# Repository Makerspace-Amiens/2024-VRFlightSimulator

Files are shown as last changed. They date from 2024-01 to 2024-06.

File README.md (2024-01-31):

# Simulateur de Vol

Template pour la création d'un repo type projet pour le MakerSpace. Doc gérée via le thème [Just-The-Docs](https://just-the-docs.com) en vanilla.

## Bienvenue sur Notre Projet

Ce repository est le cœur de notre projet. Ici, vous trouverez toutes les ressources nécessaires pour comprendre, utiliser et contribuer à notre projet.

### Contenu du Repository

- **Documentation :** Toutes les documentations techniques et guides d'utilisation sont disponibles dans le dossier `docs`. Voir le site de doc associé. 
- **project :** Toutes les sources de notre projet.

### Comment Utiliser ce Repository ?

- Pour commencer, consultez la documentation dans le dossier `docs`.
- Si vous souhaitez contribuer au projet, veuillez lire nos directives de contribution.

## Contribution

Nous accueillons et apprécions toute contribution. Si vous souhaitez contribuer, veuillez consulter notre guide de contribution pour connaître nos attentes et notre processus.

## Contact

Si vous avez des questions ou des suggestions, n'hésitez pas à nous contacter.

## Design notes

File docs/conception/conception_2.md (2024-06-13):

---
layout: default
title: Commande de gaz
parent: Conception et prototypage
nav_order: 2
---

# Conception et prototypage de la commande de gaz

## Mécanisme de frein

La première contrainte rencontrée dans la conception de la commande de gaz correspond au frein des poignées lorsqu'elles sont poussées ou tirées. Pour cela, nous nous sommes orientés dans un premier temps vers un système de vérins pneumatiques fixés sous les axes de rotation des deux poignées. Malheureusement, ce système était trop encombrant et couteux dans notre application. Nous nous sommes alors orientés vers l'utilisation de joints de plomberies mis en contrainte entre une pièce fixe et la poignée. 

Nous avons donc développé un système de frein sur mesure afin de répondre spécifiquement à nos attentes. La vis fait office d'axe de rotation et permet de compresser le joint entre la pièce fixe et la poignée, l'intensité du frein peut alors être réglée individuellement sur chaque poignée. Un écrou est inséré dans la commande de gaz et un contre-écrou permet d'entrainer la vis lors de la rotation de la poignée. Une pièce s'emboitant sur ce contre-écrou et soutenue par un roulement est destinée à accueillir l'aimant permettant de mesurer la rotation de l'axe et donc le mouvement de la poignée une fois de plus à l'aide du capteur à effet Hall AS5600.

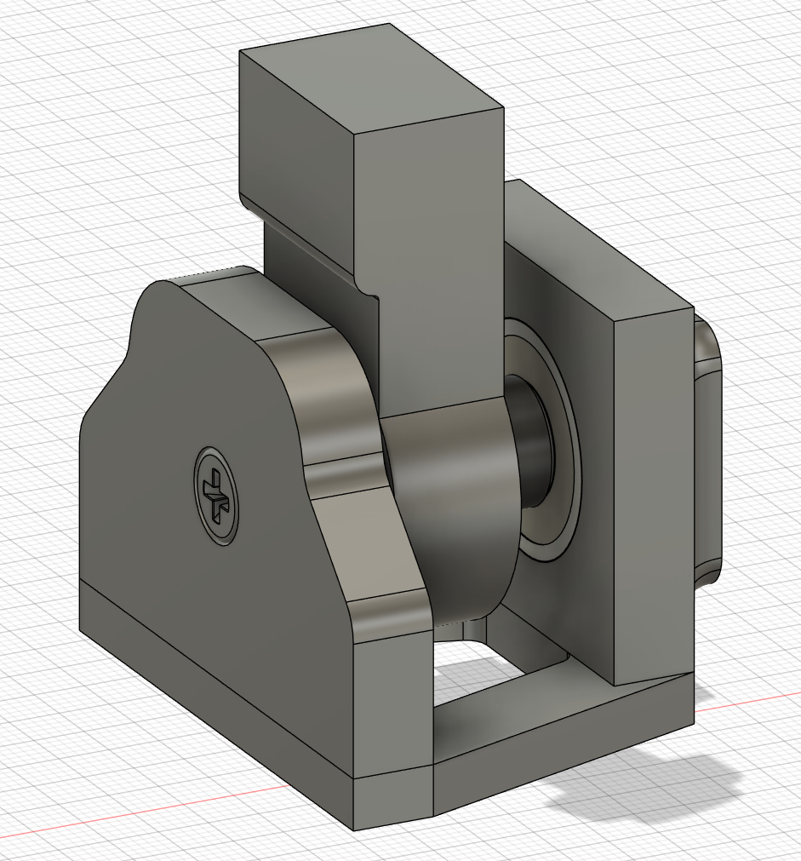
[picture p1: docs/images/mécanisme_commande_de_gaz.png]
Mécanisme cmd gaz 1


*Prototype du mécanisme de frein*

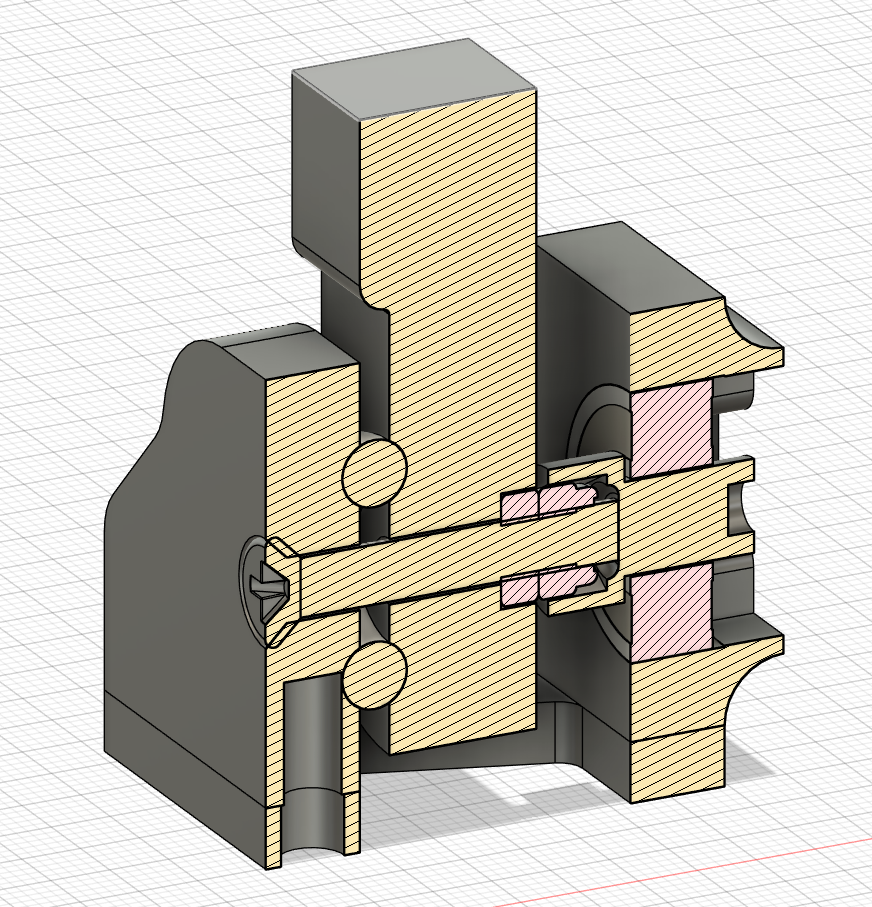
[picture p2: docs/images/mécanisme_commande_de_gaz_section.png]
Mécanisme cmd gaz 2


*Analyse de section du prototype du mécanisme de frein*

Nous avons ensuite prototypé ce mécanisme afin de valider son fonctionnement et son intégration définitive dans la commande de gaz.

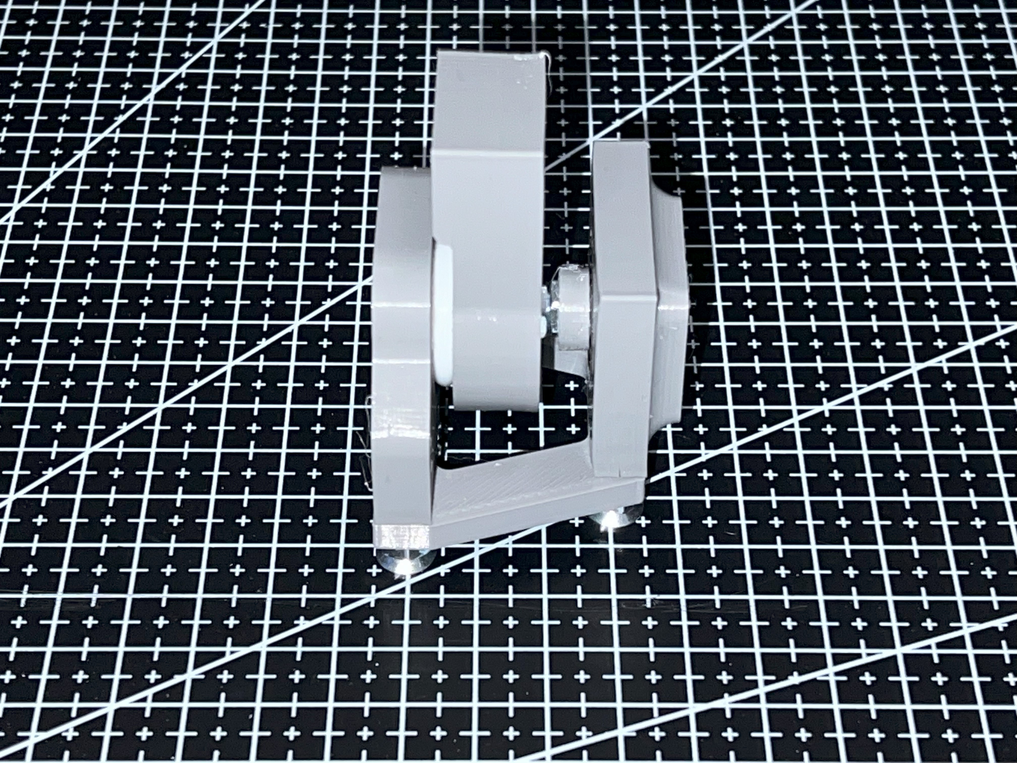
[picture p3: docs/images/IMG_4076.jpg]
Mécanisme cmd gaz 3


*Prototype du mécanisme de frein*

## Modélisation de la commande

Lors de la phase de modélisation de la commande de gaz, nous avons dans un premier temps reproduit à l'échelle 1:1 les poignées de commande de gaz d'un avion de combat A-10C tout en prenant en compte le passage des câbles des futurs composants électroniques, puis avons intégré ces commandes sur notre mécanisme de frein mis en miroir.

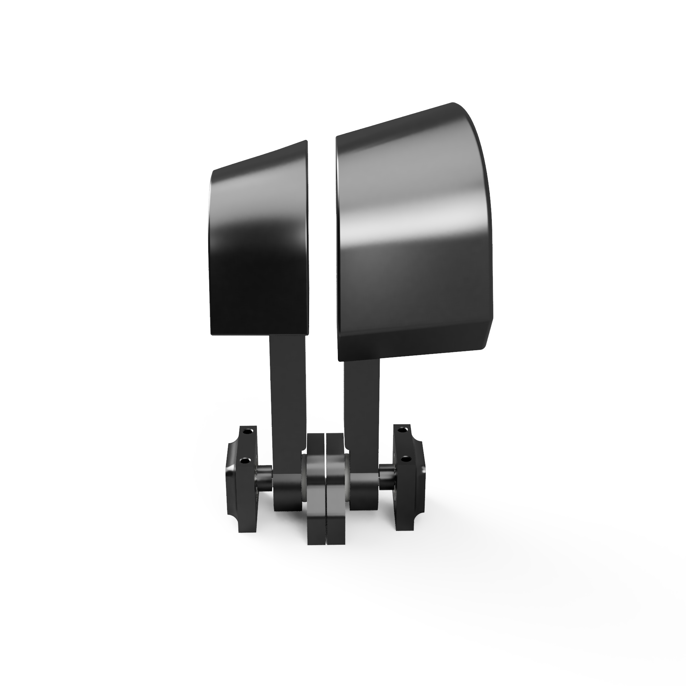
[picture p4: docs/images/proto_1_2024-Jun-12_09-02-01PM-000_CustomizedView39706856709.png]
cmd gaz 1


*Poignées des commandes de gaz*

Enfin nous avons intégré les différents composants électroniques soumis par notre cahier des charges. 

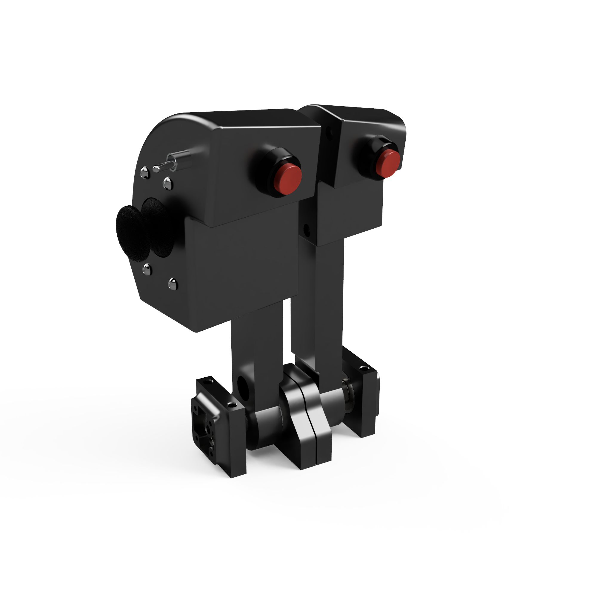
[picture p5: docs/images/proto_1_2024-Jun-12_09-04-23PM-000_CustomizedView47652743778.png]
cmd gaz 2


*Poignées des commandes de gaz avec composants électroniques*

Une fois les poignées et leur mécanisme terminés, nous avons développé un boitier quasi identique au boitier du joystick afin d'avoir un package joystick / commande de gaz cohérent.

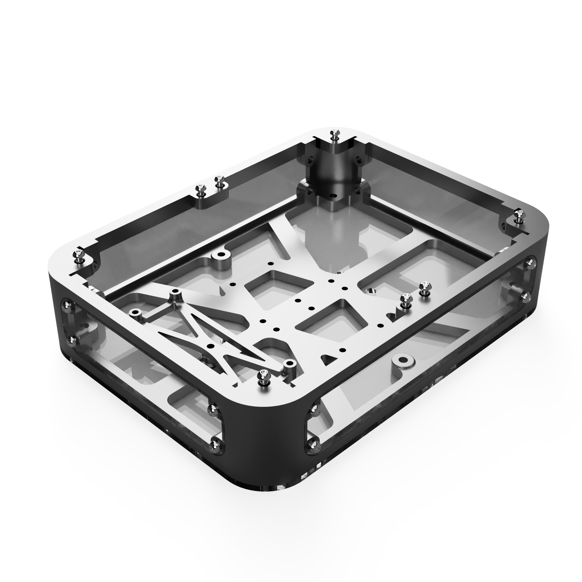
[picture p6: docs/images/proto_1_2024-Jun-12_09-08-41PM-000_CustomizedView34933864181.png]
cmd gaz 3


*Boitier de la commande de gaz*

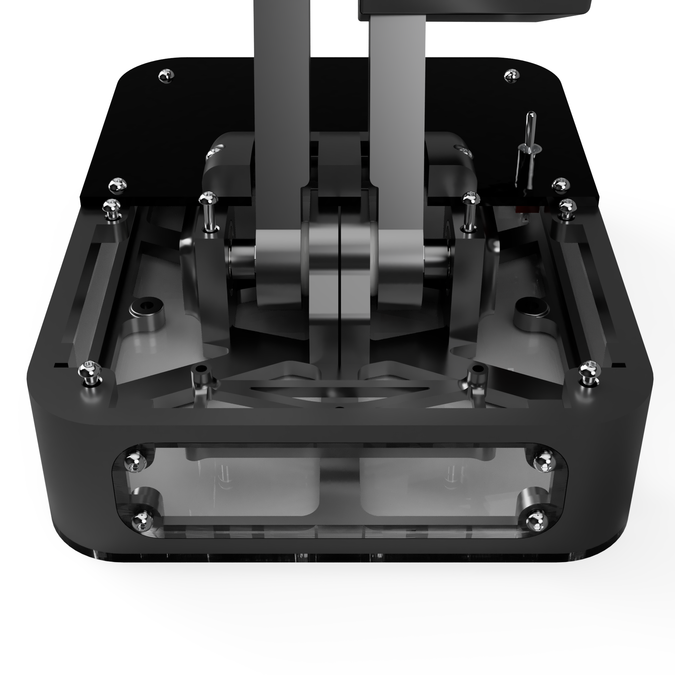
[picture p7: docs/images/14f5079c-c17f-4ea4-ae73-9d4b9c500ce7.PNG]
cmd gaz 4


*Intégration des poignées et du mécanisme dans le boitier*

Pour finir, nous avons intégré le reste des composants électroniques et développés deux encoders caps pour les encodeurs rotatifs.

**Modélisation terminée :**

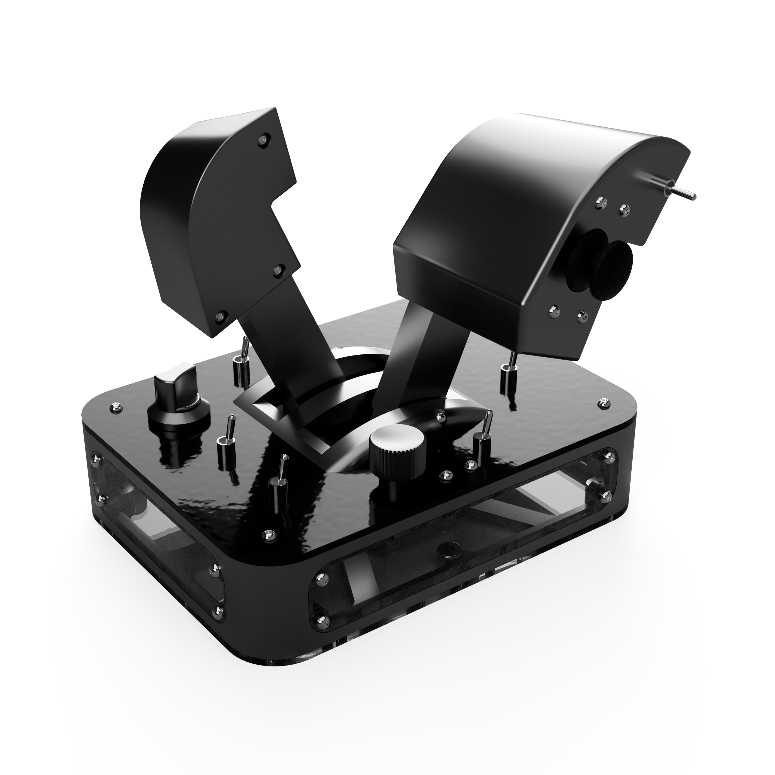
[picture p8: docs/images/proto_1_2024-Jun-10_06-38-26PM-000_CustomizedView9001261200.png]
cmd gaz 5


## Impression des composants

La modélisation achevée, nous sommes passés à la phase d'impression des composants afin de procéder au montage de la commande.

<video src="..\images\gaz_droit.mp4" controls title="Title"  style="width: 100%;"></video>

*Impression d'une partie de la poignée droite de la commande de gaz*

## Câblage des composants électroniques

Suite à l'impression des composants, nous sommes passés au câblage des différents composants électroniques présents dans la commande de gaz. De plus, nous avons utilisé le circuit imprimé du joystick afin de connecter nos composants à la carte Arduino Pro Micro.

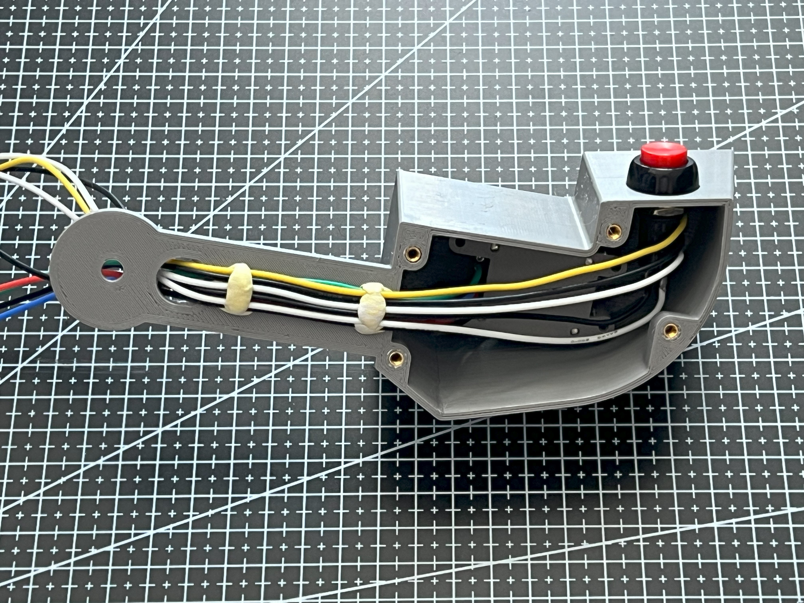
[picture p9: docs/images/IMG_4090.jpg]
cmd gaz 6


*Photo du câblage de la poignée gauche*

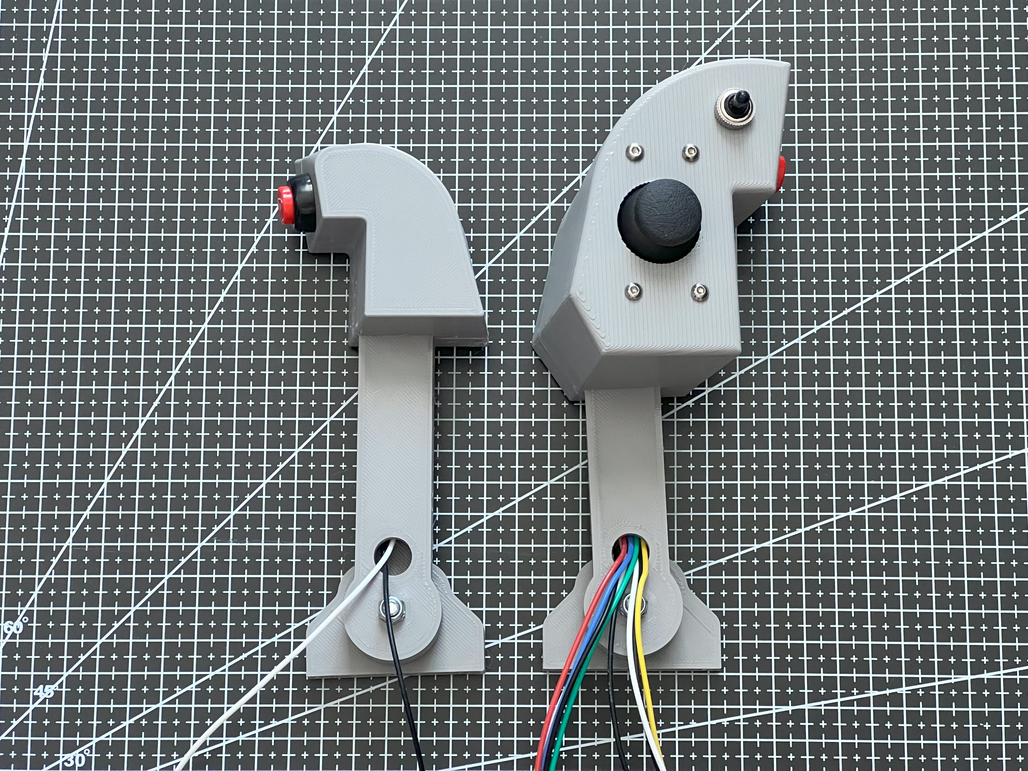
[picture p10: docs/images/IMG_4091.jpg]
cmd gaz 7


*Photo des deux poignées cablées*

Ne possédant plus de connecteurs JST, nous avons soudé les composants directement sur le PCB.

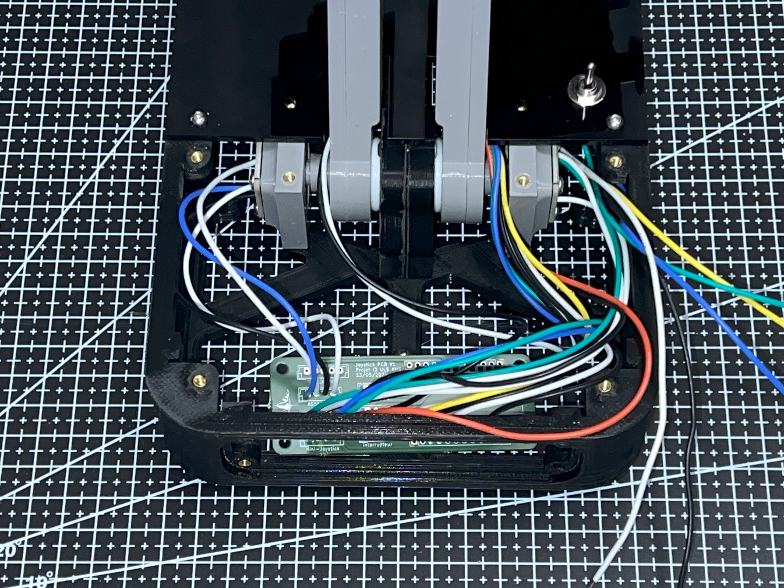
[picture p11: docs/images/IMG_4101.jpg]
cmd gaz 8


## Découpe laser

Afin de procéder au montage final, nous avons effectué les découpes et gravures nécessaires au laser avec des plaques d'acrylique 3 mm.

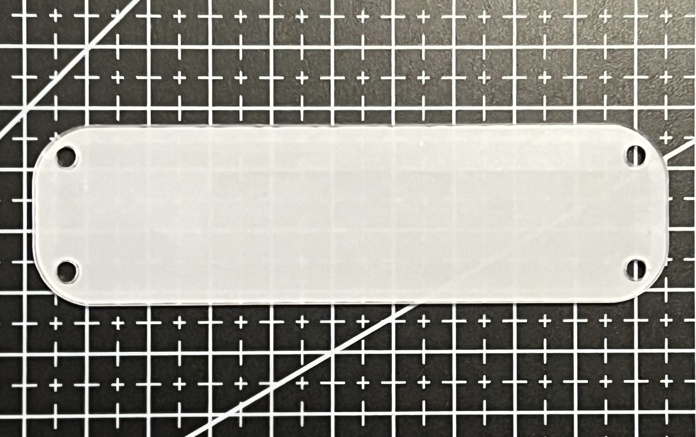
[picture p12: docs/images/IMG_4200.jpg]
cmd gaz 9


*Face du boitier découpée au laser*

<video src="..\images\decoupe.mp4" controls title="Title"  style="width: 100%;"></video>

*Découpe laser de la partie supérieure du boitier*

## Montage final

Tous les éléments composant notre commande étant opérationnels, nous sommes passés au montage final de la commande de gaz.

***Commande de gaz finalisée :***

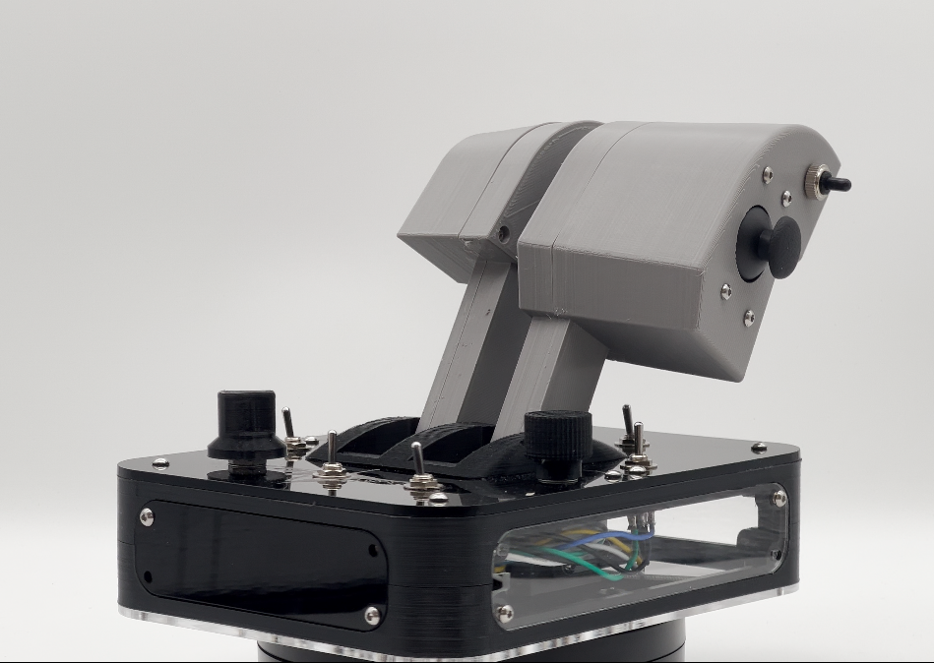
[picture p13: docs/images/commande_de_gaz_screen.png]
cmd gaz 10


***Model 3D du joystick :***

<script type="module" src="https://ajax.googleapis.com/ajax/libs/model-viewer/3.4.0/model-viewer.min.js"></script>

<model-viewer src="..\images\commande_de_gaz.glb" ar ar-modes="webxr scene-viewer quick-look" camera-controls tone-mapping="commerce" poster="..\images\poster_commande_de_gaz.webp" shadow-intensity="1"></model-viewer>

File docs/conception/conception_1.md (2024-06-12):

---
layout: default
title: Joystick
parent: Conception et prototypage
nav_order: 1
---

# Conception et prototypage du joystick

## Base du joystick

### Prototypage du capteur AS5600

Avant de se lancer dans la modélisation du mécanisme du joystick, nous sommes passés par une phase de prototypage des capteurs à effet Hall AS5600 afin de découvrir leur fonctionnement et nous préparer à la programmation de ces derniers. Le but de cette manoeuvre consiste en grande partie à ne pas se faire surprendre lors de leur intégration au mécanisme aussi bien lors de la phase de modélisation avec la tolérance de distance entre le capteur et l'aimant mais également lors de sa programmation.

Nous avons donc modélisé une pièce accueillant un roulement, un axe possédant à son extrémité un aimant et le capteur AS5600 :

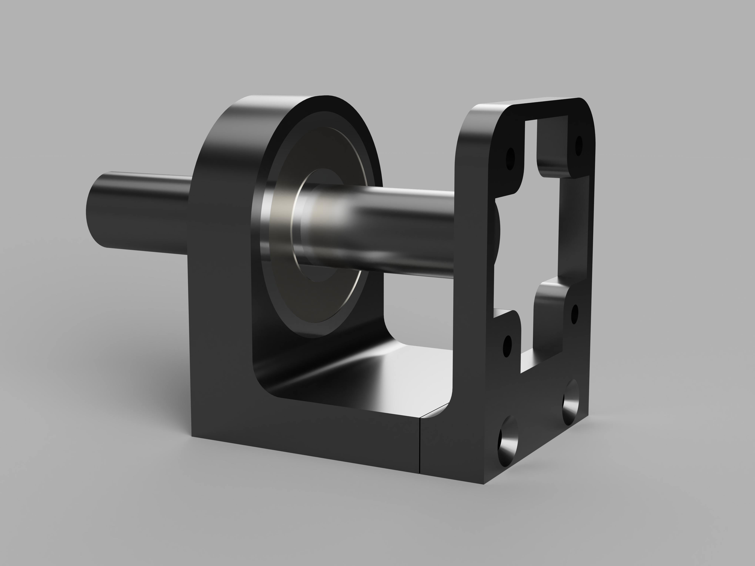
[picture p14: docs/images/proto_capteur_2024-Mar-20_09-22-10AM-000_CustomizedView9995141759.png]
Proto capteur AS5600


*Rendu 3D de la pièce destinée à prototyper un capteur AS5600*

Cette pièce a été imprimée par une imprimante 3D Artillery Sidewinder X2 utilisant la technologie de dépôt de filament fondu (FDM) :

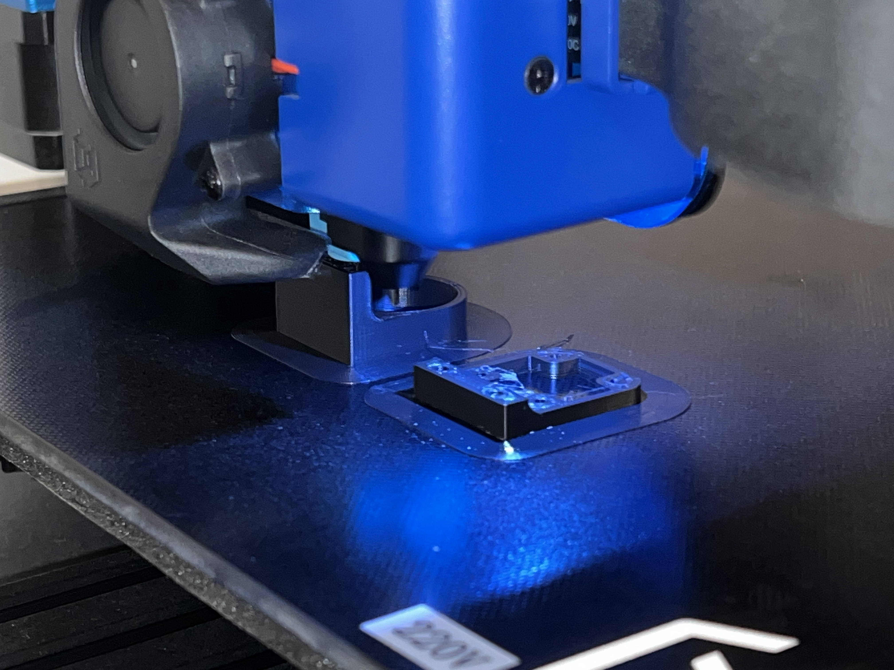
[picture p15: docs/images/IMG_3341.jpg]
Proto capteur AS5600 2


*Photo de la pièce destinée à prototyper un capteur AS5600 en cours d'impression*

Enfin nous avons prototypé ce capteur à l'aide de la carte électronique Arduino Pro Micro et d'un bouton poussoir.

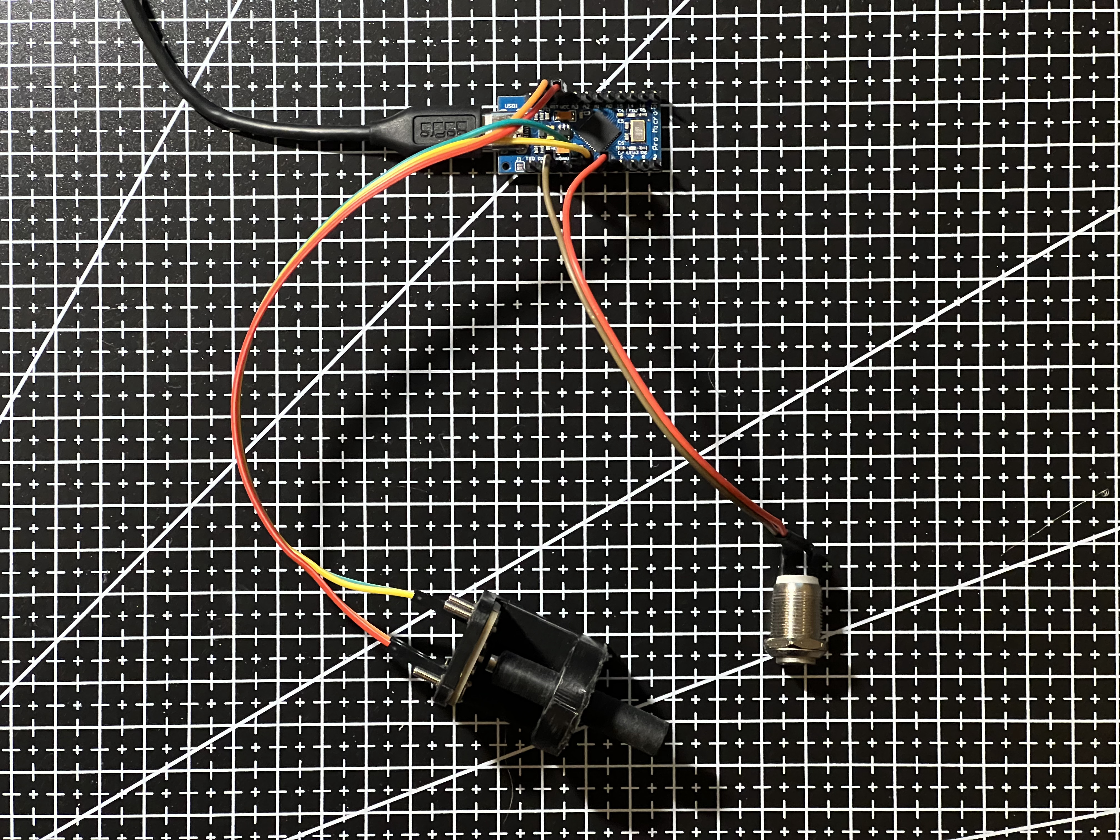
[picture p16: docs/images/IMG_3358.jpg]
Proto capteur AS5600 3


### Modélisation du mécanisme

Suite au prototypage des capteurs à effet Hall, nous sommes passés par une phase de modélisation du mécanisme en s'inspirant du mécanisme de retour de force choisit lors de la phase d'étude et choix techniques. Nous avons notamment intégré lors de cette modélisation, les composants mécaniques mais également les vis et écrous, ce qui est une bonne pratique pour ne pas avoir de surprise au montage. Pour information, seuls les patins rouges sont directement issus d'une modélisation existante.

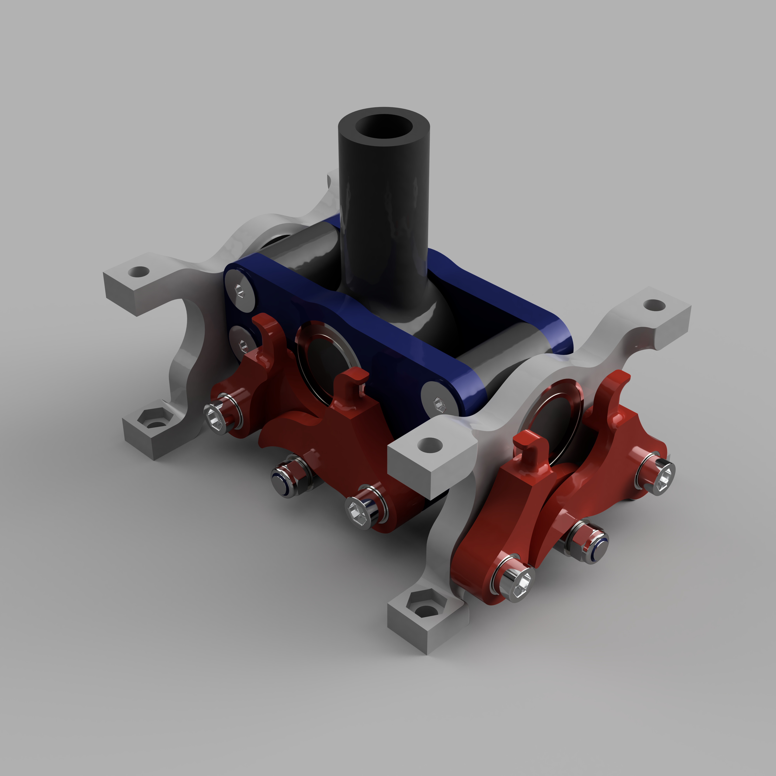
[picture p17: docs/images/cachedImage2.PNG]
Mecanisme_v1.1


*Rendu 3D de la première version du mécanisme du joystick*

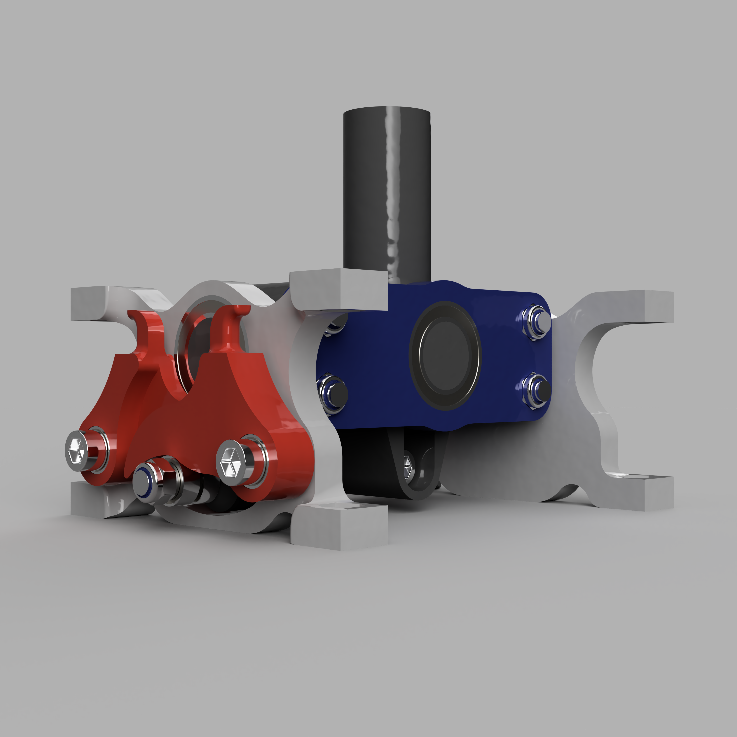
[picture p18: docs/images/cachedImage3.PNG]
Mecanisme_v1.2


*Rendu 3D de la première version du mécanisme du joystick*

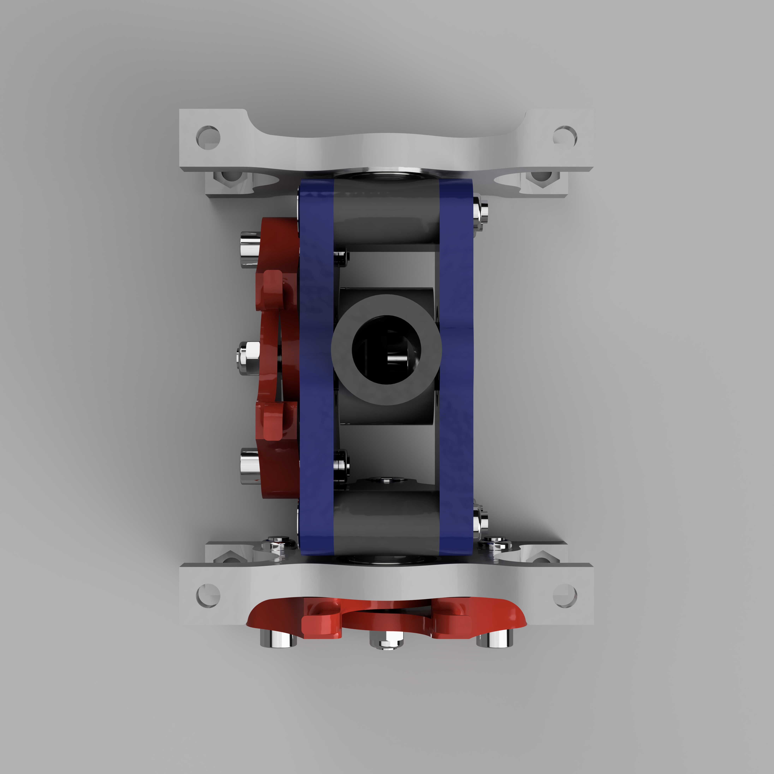
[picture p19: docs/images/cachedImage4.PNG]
Mecanisme_v1.3


*Rendu 3D de la première version du mécanisme du joystick*

### Prototypage du mécanisme

#### Prototypage matériel

Afin d'entamer la phase de prototypage du mécanisme du joystick, nous avons imprimé ses différents composants en 3D puis les avons nettoyés.

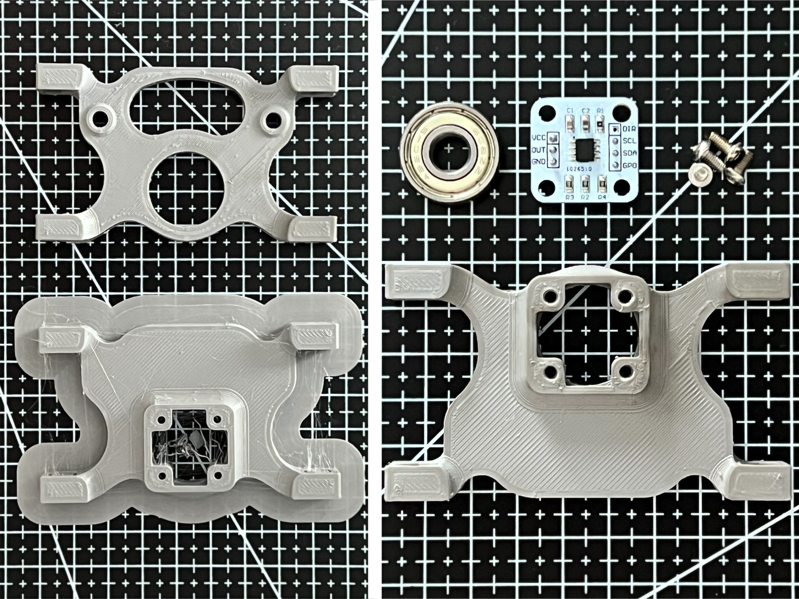
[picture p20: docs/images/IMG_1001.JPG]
Mecanisme_v1.4


*Composants du mécanisme imprimés en 3D*

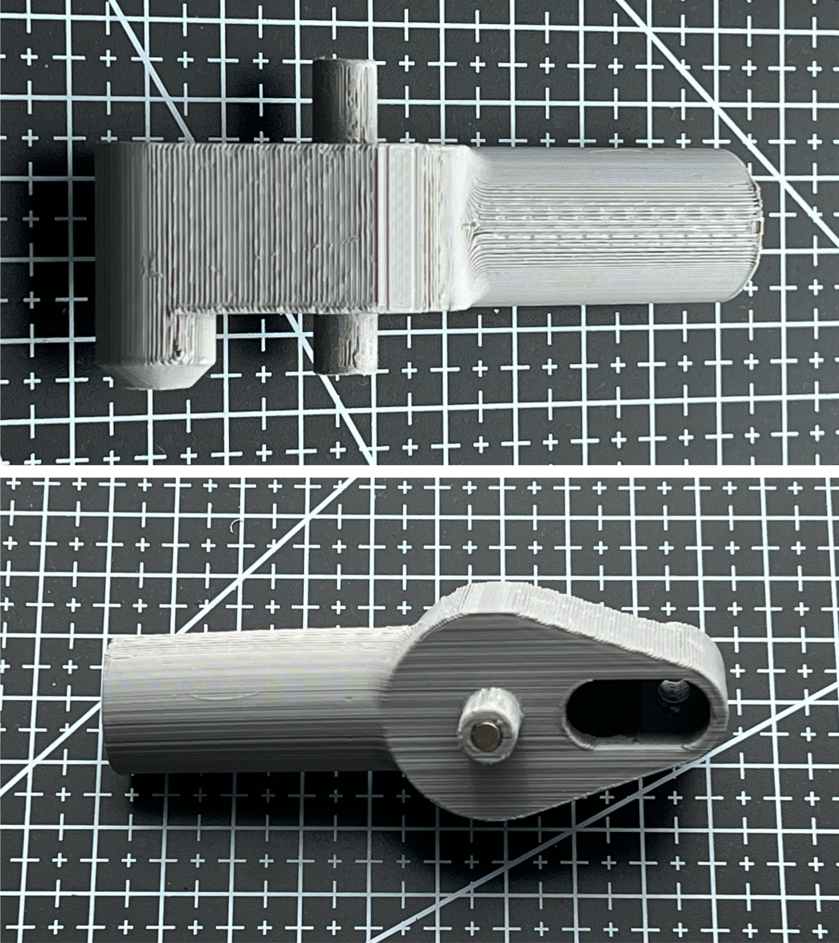
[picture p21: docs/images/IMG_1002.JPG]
Mecanisme_v1.5


*Composants du mécanisme imprimés en 3D*

Puis nous sommes passés au montage et à la programmation des capteurs.

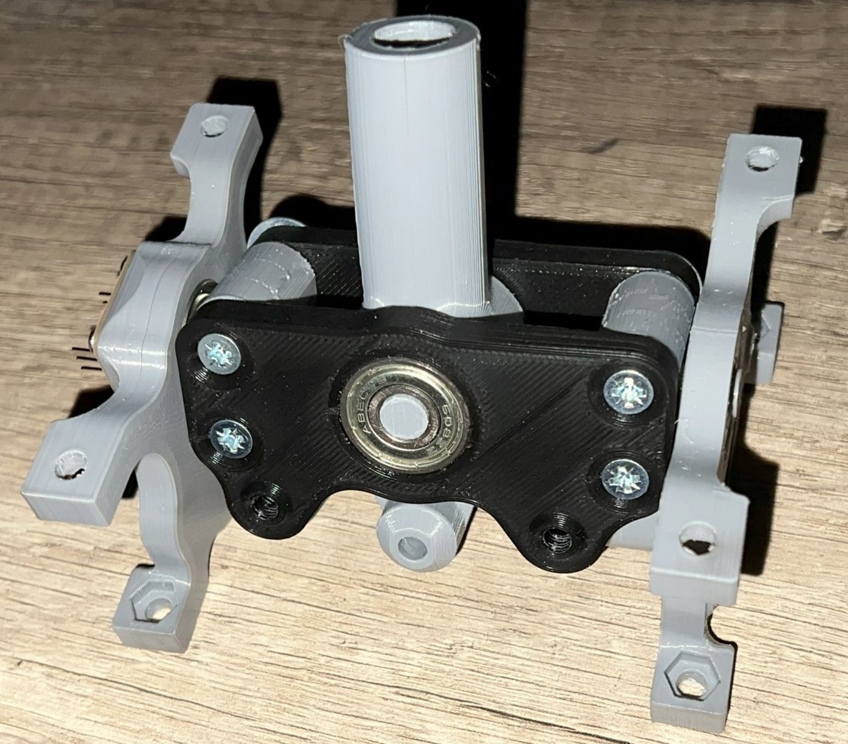
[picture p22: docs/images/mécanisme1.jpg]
Mecanisme_v1.6


*Mécanisme en cours de montage*

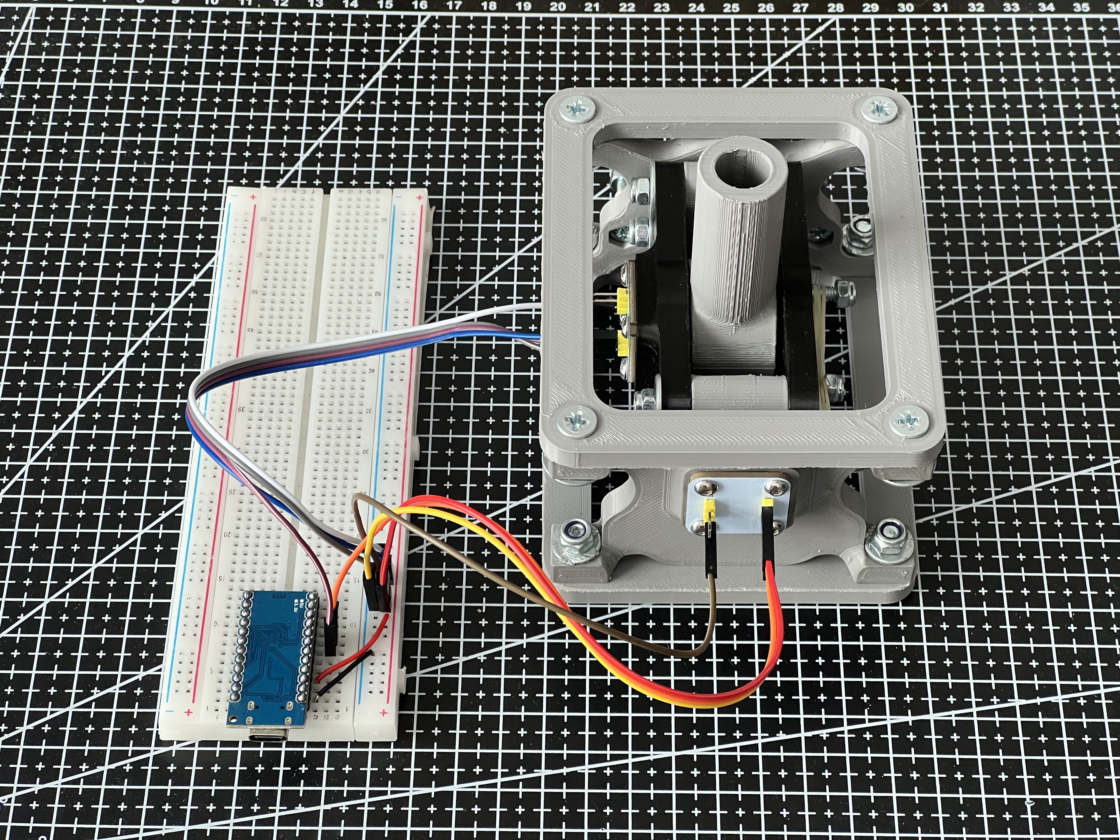
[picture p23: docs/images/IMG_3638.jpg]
Mecanisme_v1.7


*Mécanisme monté pour prototypage*

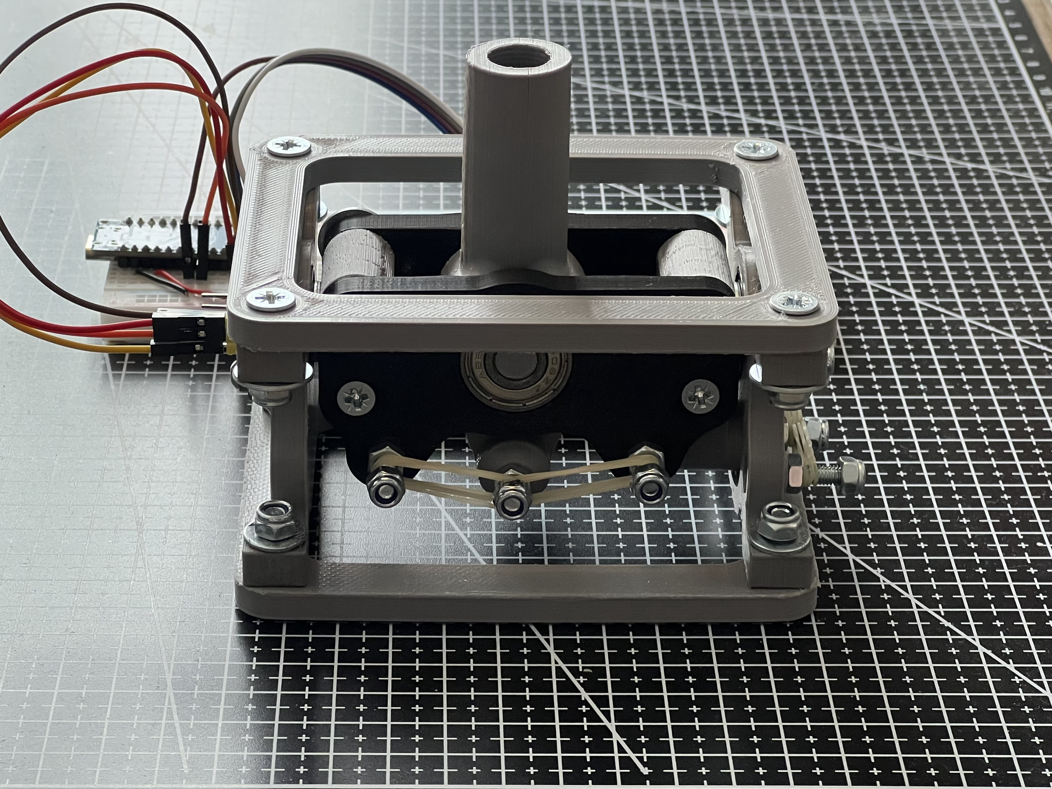
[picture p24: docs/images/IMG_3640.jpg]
Mecanisme_v1.8


*Mécanisme monté pour prototypage*

#### Prototypage logiciel

A cette étape du projet, nous avons eu l'occasion de commencer la programmation du joystick. Nous avons utilisé l'environnement de développement Arduino IDE aisni que la bibliothèque Jostick.h afin de programmer et interfacer notre carte électronique notamment dans l'utilisation de capteurs AS5600. 

Voici l'algorigramme de notre programme :

Algo

*Algorigramme du programme du joystick*

Interface de test

*Interface de test du joystick sous Windows 10*

### Première difficultée physique rencontrée

Une fois les capteurs programmés, une première difficulté s'est confrontée à nous lors du test de ce dernier, la casse d'un des axes du mécanisme dû à un décollage entre deux couches de filament. La force s'appliquant perpendiculairement à l'axe, ce dernier a cédé sous le poids de notre bras.

Ancien axe du mécanisme

*Axe X inférieur du mécanisme cassé*

Nous avons donc amélioré notre mécanisme en renforçant chaque axe par une vis M3. De plus, nous avons modifié la base de la poignée afin de faciliter son câblage avec une coupe en son centre et ajouté un mécanisme d'attache poignée afin de permettre la fixation de la future poignée sur le mécanisme.

Nouvel axe du mécanisme

*Nouvel axe du mécanisme renforcé*

Nouvel axe du mécanisme 2

*Analyse de section du renforcement de l'axe*

Evolution mécanisme

*Evolution du mécanisme*

### Mécanisme final

La modélisation terminée, nous sommes passés à l'impression des différents composants du mécanisme final et à son assemblage.

<video src="..\images\20240418_222930.mp4" controls title="Title"  style="width: 100%;"></video>

*Impression 3D de composants du mécanisme*

Composants mécanisme

*Quelques composants du mécanisme*

**Voici le mécanisme du joystick terminé :**

***Rendus 3D :***

Mécanisme final 1

*Mécanisme final du joystick*

Mécanisme final 2

*Mécanisme final du joystick*

***Vidéo 3D du montage :***

<video src="..\images\Vidéo-montage-mecanisme-joystick.mp4" controls title="Title"  style="width: 100%;"></video>

***Model 3D du mécanisme :***

<script type="module" src="https://ajax.googleapis.com/ajax/libs/model-viewer/3.4.0/model-viewer.min.js"></script>

<model-viewer src="..\images\mécanisme_final_joystick.glb" ar ar-modes="webxr scene-viewer quick-look" camera-controls tone-mapping="commerce" poster="..\images\poster_mécanisme_final_joystick.webp" shadow-intensity="1"></model-viewer>

---

## Poignée du joystick

### Design de la poignée

Possédant dès à présent un mécanisme fonctionnel et répondant à nos attentes, nous nous sommes penchés sur le développement d'une poignée de joystick sur mesure s'inspirant du joystick de l'avion de chasse F-16.

Le développement d'une telle pièce étant délicat d'un point de vue ergonomique, nous nous sommes inspirés d'une modélisation existante du joystick du F-16 afin d'obtenir les différentes dimensions importantes (hauteur/largeur/profondeur/...) dans le but d'éviter une phase de prototypage ergonomique.

Modélisation existante poignée

*Modélisation existante utilisée dans le développement de notre poignée*

Avant de nous lancer dans la modélisation, nous avons déssinés sur des rendus le design attendu lors de la phase de modélisation de cette poignée. 

Design attendu poignée

*Design attendu de la poignée*

Design attendu poignée

*Design attendu de la poignée*

Design attendu poignée

*Design attendu de la poignée*

### Développement du hat-switch

Notre cahier des charges incluant un hat-switch, nous avons décidé de développer ce dernier sur mesure car la disponibilité et le prix de ce composant étaient un frein dans son intégration au sein de notre joystick. Nous sommes donc passés par une étape de modélisation puis de prototypage.

Modélisation hat-switch 1

*Modélisation de la première version du hat_switch*

Après de nombreuses corrections de dimensions, nous sommes parvenus à un résultat satisfaisant. 

Modélisation hat-switch 1

*Prototypes de la première version du hat_switch*

Malheureusement, en vue de l'encombrement de notre hat-switch au sein de la poignée, nous avons retravaillé sa conception afin de faciliter son intégration entre les différents composants présents. Outre cela, nous avons développé un circuit imprimé sur-mesure à l'aide du logiciel KiCad.

Modélisation hat-switch 1

*Circuit électronique du PCB du hat-switch*

Modélisation hat-switch 1

*Modélisation du hat-switch final*

### Modélisation et prototypage de la poignée

Nous avons ensuite commencé la modélisation de cette poignée avec une méthode de modélisation habituelle : la modélisation solide. Cela nous permet de fixer les différentes contraintes de formes afin de simplifier la suite de la modélisation. Pour information, aucun composant de notre modélisation n'a été tiré de la modélisation existante.

Modélisation solide poignée

*Modélisation solide de la poignée*

Modélisation solide poignée

*Modélisation solide de la poignée*

Cette première étape de modélisation nous a permis de passer à une seconde méthode de modélisation : la modélisation surfacique. Cette méthode étant très compliquée à prendre en main, nous avons rencontré de nombreuses difficultés dans son utilisation.
Après plus d'une trentaine de prototypes de modélisation, nous avons réussi à aboutir à une modélisation convenable de la poignée où nous avons eu l'occasion d'intégrer le système de gâchette ainsi que les différents composants électroniques que nous avons fixés dans notre cahier des charges.

Modélisation poignée finale

*Modélisation finale de la poignée*

Modélisation poignée finale

*Modélisation finale de la poignée*

Une fois de plus, nous avons imprimé et nettoyé les différents composants de la poignée afin de procéder à son montage.

<video src="..\images\poignée-droite.mp4" controls title="Title"  style="width: 100%;"></video>

*Impression 3D de la partie droite de la poignée*

Poignée joystick

*Parties latérales de la poignée avant et après nettoyage*

***Vidéo 3D du montage :***

<video src="..\images\Vidéo-montage-poignée-joystick.mp4" controls title="Title"  style="width: 100%;"></video>

***Model 3D de la poignée :***

<script type="module" src="https://ajax.googleapis.com/ajax/libs/model-viewer/3.4.0/model-viewer.min.js"></script>

<model-viewer src="..\images\poignée_finale.glb" ar ar-modes="webxr scene-viewer quick-look" camera-controls tone-mapping="commerce" poster="..\images\poster_poignée_finale.webp" shadow-intensity="1"></model-viewer>

---

## Intégration de la poignée

Les éléments principaux composant notre joystick étant développés et remplissents nos attentes, nous sommes passés à la dernière phase du développement du joystick, l'intégration de la poignée au mécanisme. Pour cela, nous avons commencé par nous pencher sur la création du boitier destiné à accueillir le mécanisme ainsi que l'électronique de notre projet.

### Création du boitier

L'objectif de ce boitier est d'accueillir et de protéger le mécanisme et les composants électroniques de ce joystick tout en laissant entrevoir les éléments du mécanisme en fonctionnement. Afin d'obtenir un boitier solide tout en prenant en compte les contraintes de l'impression 3D, nous avons développé une base coupée en son centre à l'horizontale permettant une impression en deux parties à plat sans supports destinée à accueillir des plaques en acrylique d'une épaisseur de 3 mm découpés à l'aide d'une découpeuse laser. Ces plaques sont transparentes afin de laisser apparaître les entrailles de notre commande à l'exception de la partie supérieure qui quant à elle est gravée du logo de notre groupe réalisé à l'occasion de ce projet.

Boitier joystick 1

*Modélisation du boitier sans mécanisme*

Boitier joystick 2

*Modélisation du boitier avec mécanisme*

Enfin nous avons imprimé les éléments constituants la base de ce boitier puis effectué les découpes laser nécessaires.

<video src="..\images\20240516_203518_h264.mp4" controls title="Title"  style="width: 100%;"></video>

*Impression 3D de la partie inférieure de la base du boitier*

Boitier joystick 3

*Partie supérieure de la base du boitier*

### Développement du circuit imprimé

Afin de rendre la poignée du joystick interchangeable, nous avons décidé de développer un PCB sur-mesure dans le but de simplifier la connexion des composants électroniques en plus de les rendre modulables à l'aide de connecteurs JST 2,56 mm. De plus, ce PCB sert de base universelle dans la connexion de composants sur une carte Arduino Pro Micro, ce qui la rend compatible dans le cadre de la connexion des composants de la commande de gaz.

Afin de développer cette carte électronique, nous avons une fois de plus utilisé le logiciel KiCad puis y avons importé une bibliothèque comprenant la schématique et l'empreinte de notre carte électronique programmable. Dans un premier temps, nous nous sommes penchés sur la schématique de notre PCB en effectuant les connexions nécessaires de la carte électronique aux connecteurs JST après avoir défini le nombre total de câbles traversant le mécanisme pour arriver aux composants placés dans la poignée. Nous avons également relié chaque pin de l'Arduino Pro Micro à des pins parallèles afin de garder un accès total aux pins de cette dernière, le but étant de permettre de prototyper ou de modifier nos connexions avec les composants sans changer de circuit imprimé. Enfin nous avons ajouté les perçages de notre PCB.

PCB 1

*Schématique du circuit imprimé*

Nous sommes ensuite passé à la phase de routage du circuit imprimé. Pour cela, nous avons utilisé dans un premier temps le plugin Freeroute qui nous a permis d'avoir une idée du passage des différentes pistes. Nous avons ensuite routé chaque piste à la main après avoir défini la largeur des routes à 0.5 mm, ce qui est acceptable dans notre contexte puisque l'alimentation de nos composants ne demande pas beaucoup de puissance. Enfin nous avons placé un plan de masse sur les deux faces de notre PCB afin de simplifier son routage et réduire les interferances des signaux envoyés par les composants.

PCB 2

*Circuit électronique du circuit imprimé*

La conception de notre circuit imprimé terminé, nous l'avons intégré dans notre modélisation.

PCB 3

*Rendu 3D du circuit imprimé*

PCB 3

*Rendu 3D du circuit imprimé intégré dans le boitier du joystick*

Après réception de ces circuits imprimés commandés auprès du fournisseur spécialisé dans ce domaine Aisler, nous avons eu l'occasion de procéder à la soudure des connecteurs JST et des broches de pins mâles et femelles.

PCB 4

*Photo du circuit imprimé vierge et soudé*

### Câblage des composants électroniques

Dans le cadre du câblage des composants électroniques de la poignée du joystick, nous avons utilisé du câble électrique en PVC 24/AWG, une épaisseur de câble largement suffisante dans notre application. Nous avons protégé toutes les connexions à l'aide de gaine thermo-rétractable et installés les connecteurs JST à l'aide d'une pince à sertir.

Câblage 1

*Photo du câblage des composants électroniques du joystick*

Câblage 2

*Photo du câblage des composants électroniques du joystick*

## Montage final

Tout les élements composant notre commande étants opérationnels, nous sommes passés au montage final du joystick.

***Vidéo 3D du montage :***

<video src="..\images\Vidéo-montage-joystick.mp4" controls title="Title"  style="width: 100%;"></video>

***Model 3D du joystick :***

<script type="module" src="https://ajax.googleapis.com/ajax/libs/model-viewer/3.4.0/model-viewer.min.js"></script>

<model-viewer src="..\images\joystick.glb" ar ar-modes="webxr scene-viewer quick-look" camera-controls tone-mapping="commerce" poster="..\images\poster_joystick.webp" shadow-intensity="1"></model-viewer>

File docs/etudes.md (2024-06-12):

---
layout: default
nav_order: 4
title: Études et choix techniques
---

# Études et choix techniques

## Inspiration et Conception

Notre projet de simulateur de vol s'est largement inspiré des commandes de vol de véritables appareils militaires pour assurer un réalisme et une immersion maximum. Plus spécifiquement, le joystick de notre simulateur est inspiré de celui du F-16, tandis que la commande de gaz s'inspire de celle du A-10C.

### Capteurs à Effet Hall AS5600

Pour la mesure des mouvements de nos commandes, nous avons choisi d'utiliser des capteurs à effet Hall AS5600. L'effet Hall est un phénomène où un courant électrique dans un matériau génère une petite tension lorsqu'il traverse un champ magnétique, permettant de détecter ce champ et de ce fait la position angulaire d’un aiment. Ces capteurs offrent plusieurs avantages par rapport aux potentiomètres traditionnels, notamment :

•	**Absence de Frottement** : Les capteurs à effet Hall fonctionnent sans contact physique entre les composants, éliminant ainsi les frottements et l'usure mécanique, ce qui améliore la durabilité.

•	**Précision Accrue** : Les capteurs à effet Hall offrent une précision de mesure supérieure, essentielle pour des commandes de vol où la réactivité et la précision sont cruciales.

•	**Durée de Vie Allongée** : La nature sans contact de ces capteurs prolonge leur durée de vie comparée aux potentiomètres.

image d'inspiration

*Capteur à effet Hall AS5600*

### Roulements 608ZZ

Pour assurer une fluidité optimale lors de l'utilisation du joystick et de la commande de gaz, chaque axe de rotation est monté sur des roulements 608ZZ. Ces roulements sont choisis pour plusieurs raisons :

•	**Disponibilité et Coût** : Le roulement 608ZZ est très commun et facile à trouver dans le commerce à un prix raisonnable.

•	**Dimensions et Intégration** : Ses dimensions permettent une grande flexibilité d'intégration dans notre conception.

•	**Fluidité de Mouvement** : Les roulements 608ZZ offrent une résistance minimale, assurant des mouvements fluides et précis.

image d'inspiration

*Roulement 608zz*

### Système de Retour de Force du joystick

Le retour de force dans notre joystick est conçu pour simuler la résistance rencontrée dans le joystick d'un véritable avion de chasse. Après quelques recherches sur les systèmes éxistants, nous nous sommes orientés vers un système avec un roulement en contrainte sur une pièce montée sur ressort en dessous de la base pour contrôler les axes X et Y. 

image d'inspiration

*Premier système de retour de force*

Cependant, pour des raisons d'encombrement, nous souhaitions retrouver ce type de système déplacé à l'extrémité opposée des capteurs AS5600. Nous nous sommes donc inspirés de ce système de retour de force peu encombrant et ayant une possibilité de réglage de dureté et de linéarité afin développer notre système de retour de force :

image d'inspiration

*Second système de retour de force*

### Composants Électroniques

Le choix des composants électroniques pour la poignée du joystick et la commande de gaz a été déterminé par les fonctionnalités attendues et la nécessité d'un encombrement minimal. Nous avons choisi :

•	**Joystick** : Trois boutons poussoirs, un mini joystick, un hat-switch et un interrupteur à bascule. Face à la difficulté de trouver un hat-switch à un prix abordable, nous avons décidé d'en développer un nous-mêmes.

•	**Commande de Gaz** : Six interrupteurs à bascule, deux boutons poussoirs, deux encodeurs rotatifs et un mini joystick.

image d'inspiration

*Composants électroniques utilisés dans le joystick*

### Carte Arduino Pro Micro

Pour la partie électronique programmable, nous avons opté pour une carte Arduino Pro Micro en raison de ses nombreux avantages :

•	**Facilité de Programmation** : La carte est facilement programmable avec des librairies compatibles bien documentées.

•	**Rapidité et Faible Latence** : Elle offre une exécution rapide des commandes avec une latence minimale, essentielle pour un simulateur de vol en temps réel.

•	**Accessibilité et Coût** : Les clones de la carte Arduino Pro Micro sont facilement disponibles dans le commerce à des prix très abordables.

•	**Compatibilité** : Sa compatibilité avec divers périphériques d'interfaçage répond parfaitement à nos besoins techniques.

image d'inspiration

*Arduino Pro Micro*

# Conclusion

Les choix techniques effectués pour notre simulateur de vol ont été guidés par la recherche d'une précision, d'une durabilité et d'une immersion maximales. Les capteurs à effet Hall AS5600, les roulements 608ZZ, le système de retour de force optimisé et les composants électroniques soigneusement sélectionnés contribuent tous à un simulateur réaliste et performant. Le choix de la carte Arduino Pro Micro assure une gestion efficace et rapide de l'ensemble du système, rendant notre simulateur à la fois innovant et accessible.

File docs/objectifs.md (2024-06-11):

---
layout: default
nav_order: 3
title: Objectifs du projet
---

# Contexte du Projet

Dans le cadre de notre projet de 3ème année au sein de l'école d'ingénieur UniLaSalle Amiens, 75h sont dédiées à la réalisation d'un projet permettant de mettre en œuvre et approfondir différentes connaissances acquises durant les années précédentes dans des domaines techniques tels que l'électronique, la modélisation ou encore la programmation mais également de développer des compétences personnelles tels que la gestion d'équipe ou le coworking.

Certains membres de notre équipe ayant réalisé dans le cadre du projet d'Innovation Technologique et Eco-Concéption durant notre seconde année de cycle préparatoire, un volant type F1 fonctionnel dédié à l'utilisation en Sim Racing. Nous avons décidés de nous lancer une fois de plus dans la domaine de la simulation avec la réalisation d'un simulateur de vol.

Un projet similaire ayant été abandonné il y'a quelques années, le choix de ce projet a été d'autant plus motivant dans sa concrétisation tout en utilisant les nouvelles technologies qui sont aujourd'hui à notre disposition. C'est pourquoi nous nous sommes attardés sur la création d'un simulateur d'avion de chasse utilisable en Réalité Virtuelle.

# Objectifs du Projet

Concevoir, construire et mettre en œuvre un simulateur de vol d'avion de chasse réaliste et immersif utilisable en réalité virtuelle, offrant une expérience utilisateur hautement satisfaisante.

## Objectifs Spécifiques :

### 1. Accessoires de Commande :

Concevoir et construire un joystick ainsi qu'une commande gaz offrant une précision
et une réactivité optimales, intégrés au simulateur avec une communication fiable et une
compatibilité logicielle.

### 2. Châssis sur Mesure :

Concevoir un châssis robuste en profilé aluminium pour assurer la stabilité et la
durabilité du simulateur, en veillant à son assemblage solide pour supporter efficacement les
accessoires de commande.

# Cahier des Charges

## 1. Spécifications matérielles et logicielles :

### 1.1 Casque de réalité virtuelle :

Image du casque HTC Vive Focus 3

*HTC Vive Focus 3*

### 1.2 Logiciels de simulations

Image de MFS / DCS

*Microsoft Flight Simulator 2020 / Digital Combat Simulator*

## 2. Spécifications Techniques des accessoires de commande :

### 2.1 Joystick :

  - Détection de mouvements avec capteurs à effets hall 
  - Trois boutons poussoirs
  - Hat switch 
  - Mini joystick
  - Gachette
  - Interrupteur à bascule
  - Corps et base imprimés en 3D 

**Inspirations :** 

image d'inspiration

*Thrustmaster HOTAS Warthog™ Joystick*

### 2.2 commandes de gaz : 

  - Détection de mouvements avec capteurs à effets hall
  - Deux boutons poussoirs
  - Deux encodeurs rotatifs
  - Un mini joystick 
  - Six interrupteurs à bascule
  - Corps et base imprimés en 3D 

**Inspirations :**

image d'inspiration

*Thrustmaster HOTAS Warthog™ Dual Throttle*

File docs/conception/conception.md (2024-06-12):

---
layout: default
title: Conception et prototypage
nav_order: 5
has_children: true
---

# Conception et prototypage

Bienvenue dans la section dédiée aux étapes de conception et prototypage de notre projet. Ici, vous trouverez de nombreux détails portant sur chaque étape du processus de conception et prototypage.

## Aperçu des Étapes

Le processus de conception et prototypage est divisé en plusieurs parties :

1. [Joystick](conception_1)
2. [Commande de gaz](conception_2)

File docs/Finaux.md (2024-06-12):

---
layout: default
title: Commandes terminées
nav_order: 6
---

# Joystick

Joystick

*Rendu 3D du joystick*

<video src="images/joystick(1).mp4" controls title="Title"  style="width: 100%;"></video>

*Rendu réel du joystick*

# Commande de gaz

Commande de gaz

*Rendu 3D de la commande de gaz*

<video src="images/cmd_de_gaz.mp4" controls title="Title"  style="width: 100%;"></video>

*Rendu réel de la commande de gaz*

# Gameplay

<video src="images/gameplay.mp4" controls title="Title"  style="width: 100%;"></video>

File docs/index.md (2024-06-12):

---
layout: home
nav_order: 1
title: Accueil
---

# Bienvenue sur notre site Projet Simulateur de Vol

Bienvenue dans la documentation du projet de création de commandes de simulateur de vol. Ce site a pour but de fournir toutes les informations nécessaires pour comprendre et utiliser notre projet.

Illustration vectorielle colorée avec un fond blanc, montrant un atelier équipé pour un projet de conception mécanique, électronique et informatique

## À propos du Projet

Notre projet consiste à créer de A à Z des commandes de vol utilisables sur ordinateur sur des logiciels comme microsoft flight simulator, pour cela nous avons réalisé un joystick ainsi que des commandes de gaz permettant le controle précis et intuitif de différents aéronerf.

## Poster

poster

## Vidéo

<video src="images/video_projet.mp4" controls title="Title"  style="width: 100%;"></video>

---

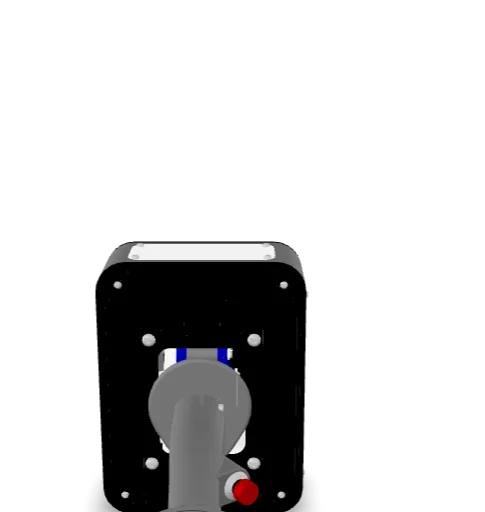
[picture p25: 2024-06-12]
docs/images/poster_joystick.webp

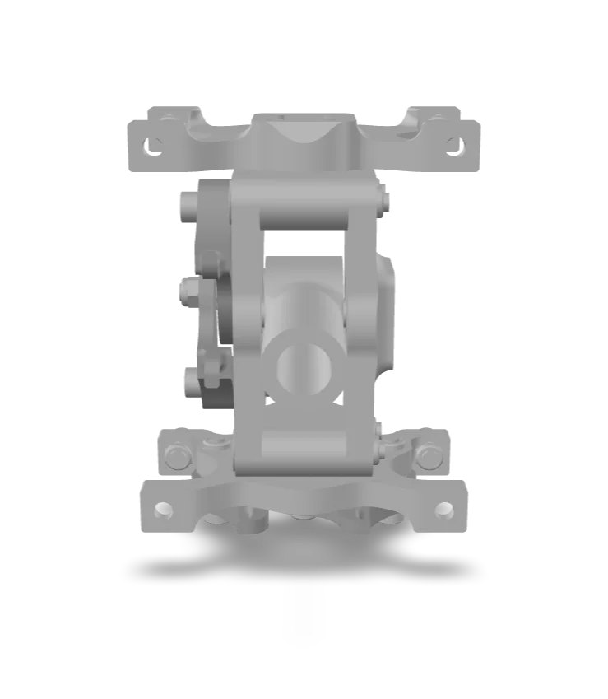
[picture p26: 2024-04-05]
docs/images/poster copy.webp

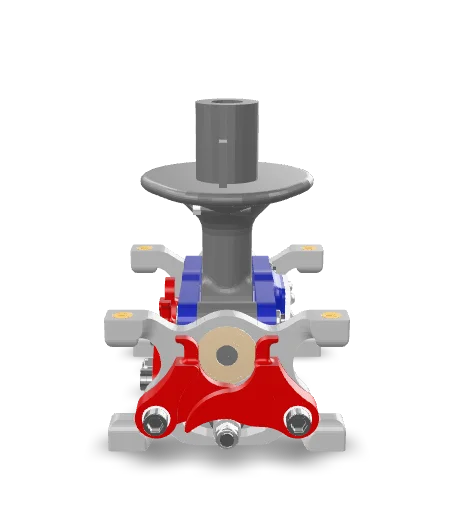
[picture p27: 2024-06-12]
docs/images/poster_mécanisme_final_joystick.webp

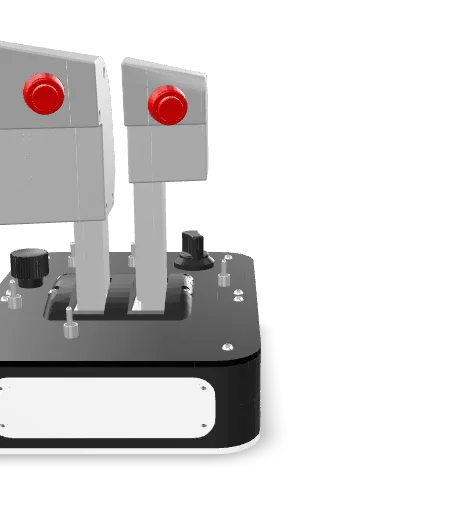
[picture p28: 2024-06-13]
docs/images/poster_commande_de_gaz.webp

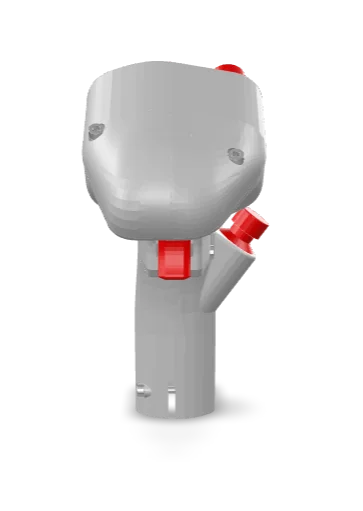
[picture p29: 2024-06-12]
docs/images/poster_poignée_finale.webp

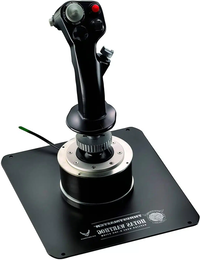
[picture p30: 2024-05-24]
docs/images/joystick_inspiration_copy.png

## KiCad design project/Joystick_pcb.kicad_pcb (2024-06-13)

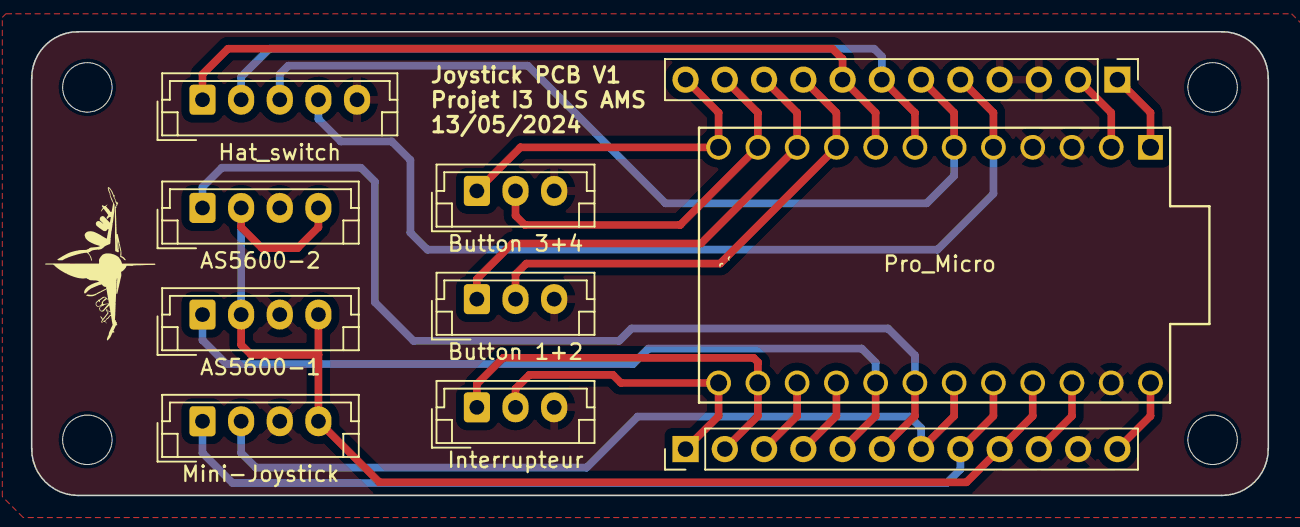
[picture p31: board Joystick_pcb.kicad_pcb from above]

Board: 2 copper layers, 80.0 x 30.0 mm, 14 parts (0 on the bottom side), 22 nets.

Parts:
H1, H2, H3, H4: MountingHole; MountingHole_3.2mm_M3
J1: AS5600-1; JST_EH_B4B-EH-A_1x04_P2.50mm_Vertical
J2: AS5600-2; JST_EH_B4B-EH-A_1x04_P2.50mm_Vertical
J3: Mini-Joystick; JST_EH_B4B-EH-A_1x04_P2.50mm_Vertical
J4: Hat_switch; JST_EH_B5B-EH-A_1x05_P2.50mm_Vertical
J5: Button 1+2; JST_EH_B3B-EH-A_1x03_P2.50mm_Vertical
J6: Button 3+4; JST_EH_B3B-EH-A_1x03_P2.50mm_Vertical
J7: Interrupteur; JST_EH_B3B-EH-A_1x03_P2.50mm_Vertical
J8, J9: Conn_01x12_Pin; PinHeader_1x12_P2.54mm_Vertical
U1: ProMicro

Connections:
2: J4.4, J8.5, U1.5 (SDA)
3: J4.3, J8.6, U1.6 (SCL)
4: J4.2, J8.7, U1.7 (D4)
5: J4.1, J8.8, U1.8 (C6)
6: J5.2, J8.9, U1.9 (D7)
7: J5.1, J8.10, U1.10 (E6)
8: J6.2, J8.11, U1.11 (B4)
9: J6.1, J8.12, U1.12 (B5)
10: J7.2, J9.1, U1.13 (B6)
11: J7.1, J9.2, U1.14 (B2)
+5V: J1.2, J1.4, J2.2, J2.4, J3.4, J9.9, U1.21 (VCC)
A0: J1.1, J9.5, U1.17 (F7)
A1: J2.1, J9.6, U1.18 (F6)
A2: J3.2, J9.7, U1.19 (F5)
A3: J3.1, J9.8, U1.20 (F4)
GND: J1.3, J2.3, J3.3, J4.5, J5.3, J6.3, J7.3, J8.3, J8.4, J9.11, U1.3 (GND), U1.4 (GND), U1.23 (GND)
unnamed: J8.1, U1.1 (TX)
unnamed: J8.2, U1.2 (RX)
unnamed: J9.3, U1.15 (B3)
unnamed: J9.4, U1.16 (B1)
unnamed: J9.10, U1.22 (RST)
unnamed: J9.12, U1.24 (RAW)

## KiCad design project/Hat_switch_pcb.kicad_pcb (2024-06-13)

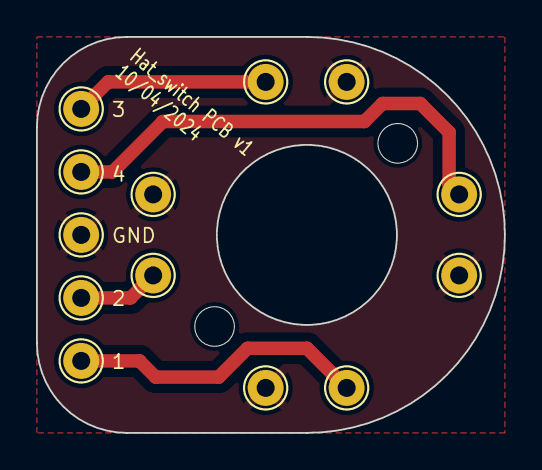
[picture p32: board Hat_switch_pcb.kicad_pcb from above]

Board: 2 copper layers, 26.0 x 22.0 mm, 15 parts (0 on the bottom side), 5 nets.

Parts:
H1, H2: m2; MountingHole_2.2mm_M2
TP1, TP2, TP3, TP4, TP5, TP6, TP7, TP8, TP9, TP10, TP11, TP12, TP13: TestPoint_THTPad_D2.0mm_Drill1.0mm

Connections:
GND: TP1.1, TP6.1, TP8.1, TP10.1, TP12.1
unnamed: TP2.1, TP7.1
unnamed: TP4.1, TP9.1
unnamed: TP3.1, TP11.1
unnamed: TP5.1, TP13.1

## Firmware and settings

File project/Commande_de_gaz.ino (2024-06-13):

#include <Joystick.h>

int minX, maxX, minY, maxY;
int Variation;
Joystick_ Joystick;

void setup() {
  Joystick.begin();

  Joystick.setXAxisRange(0, 124);
  Joystick.setYAxisRange(0, 124);

  int initX = analogRead(A1);
  int initY = analogRead(A0);

  Variation = 176; // Origine à 175

  minX = initX + 4; 
  maxX = initX + 172;
  minY = initY - 4;
  maxY = initY - 180;

  pinMode(2, INPUT_PULLUP);
  pinMode(3, INPUT_PULLUP);
  pinMode(4, INPUT_PULLUP);
  pinMode(5, INPUT_PULLUP);
  pinMode(6, INPUT_PULLUP);
  pinMode(7, INPUT_PULLUP);
  pinMode(8, INPUT_PULLUP);
  pinMode(9, INPUT_PULLUP);
  pinMode(10, INPUT_PULLUP);
  pinMode(16, INPUT_PULLUP);

  pinMode(0, INPUT_PULLUP);
  pinMode(1, INPUT_PULLUP);
  pinMode(14, INPUT_PULLUP);
  pinMode(15, INPUT_PULLUP);
}

void loop() {
  int valeurAnalogiqueX = analogRead(A1);
  int valeurAnalogiqueY = analogRead(A0);

  int AxeX = map(valeurAnalogiqueX, minX, maxX, 0, 1024);
  int AxeY = map(valeurAnalogiqueY, minY, maxY, 0, 1024);

  AxeX = constrain(AxeX, 0, 1024);
  AxeY = constrain(AxeY, 0, 1024);

  Joystick.setRxAxis(AxeX);
  Joystick.setRyAxis(AxeY);


  int mini_joystick_AX = analogRead(A2);
  int mini_joystick_AY = analogRead(A3);

  int mini_joystick_X = map(mini_joystick_AX, 1024, 0, 124, 0);
  int mini_joystick_Y = map(mini_joystick_AY, 1024, 0, 0, 124);

  mini_joystick_X = constrain(mini_joystick_X, 0, 124);
  mini_joystick_Y = constrain(mini_joystick_Y, 0, 124);

  Joystick.setXAxis(mini_joystick_X);
  Joystick.setYAxis(mini_joystick_Y);
  

  Joystick.setButton(1, (digitalRead(2) == LOW));
  Joystick.setButton(2, (digitalRead(3) == LOW));
  Joystick.setButton(3, (digitalRead(4) == LOW));
  Joystick.setButton(4, (digitalRead(5) == LOW));
  Joystick.setButton(5, (digitalRead(6) == LOW));
  Joystick.setButton(6, (digitalRead(7) == LOW));
  Joystick.setButton(7, (digitalRead(8) == LOW));
  Joystick.setButton(8, (digitalRead(9) == LOW));
  Joystick.setButton(9, (digitalRead(10) == LOW));
  Joystick.setButton(10, (digitalRead(16) == LOW));
  
  Joystick.setButton(11, (digitalRead(0) == LOW));
  Joystick.setButton(12, (digitalRead(1) == LOW));
  Joystick.setButton(13, (digitalRead(14) == LOW));
  Joystick.setButton(14, (digitalRead(15) == LOW));

  delay(20);
}

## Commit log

2024-06-12 Création de la section conception et prototypage
2024-06-13 Ajout PCB + code
    [Hat_switch_pcb.kicad_pcb, Joystick_pcb.kicad_pcb]
